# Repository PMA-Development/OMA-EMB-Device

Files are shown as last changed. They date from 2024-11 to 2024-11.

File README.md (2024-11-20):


<!-- PROJECT LOGO -->
<br />
<div align="center">
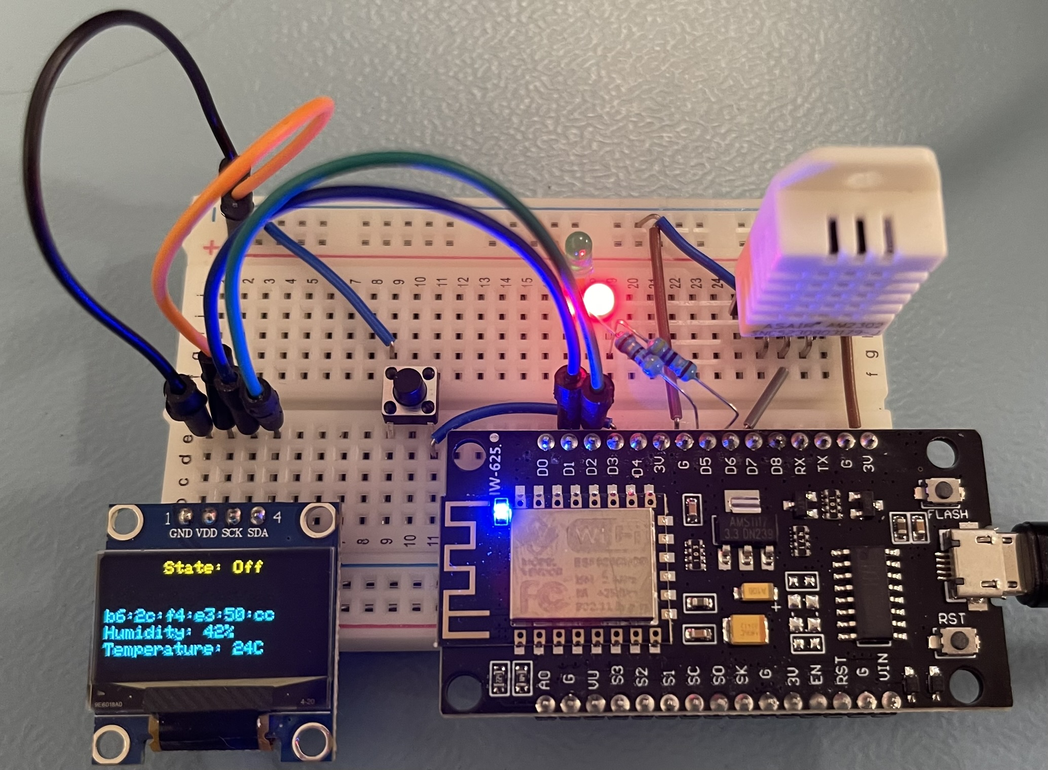
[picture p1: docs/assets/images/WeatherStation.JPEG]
Project image
    

  <h3 align="center">OMA - Embbedded Device sensors</h3>

  <p align="center">
    Weather Station, Generator and PowerDelivery sensor code for microcontroller.
    <br />
    <br />
  </p>
</div>

<!-- TABLE OF CONTENTS -->
<details>
  <summary>Table of Contents</summary>
  <ol>
    <li>
      <a href="#about-the-project">About The Project</a>
      <ul>
        <li><a href="#built-with">Built With</a></li>
      </ul>
    </li>
    <li><a href="#getting-started">Getting Started</a></li>
    <li><a href="#usage">Usage</a></li>
  </ol>
</details>

<!-- ABOUT THE PROJECT -->
## About The Project

### Libraries used

Here are the libaries used in this project, these libaries is a must have, to be able to run the program, please remember to install the dependencies!

* [ArduinoMqttClient 0.1.8](https://github.com/arduino-libraries/WiFiNINA) by [Arduino](https://www.arduinolibraries.info/authors/arduino-libraries)
* [Adafruit BusIO 1.16.2](https://github.com/adafruit/Adafruit_BusIO) by [Adafruit](https://www.arduinolibraries.info/authors/adafruit)
* [Adafruit GFX Library 1.11.11](https://github.com/adafruit/Adafruit-GFX-Library) by [Adafruit](https://www.arduinolibraries.info/authors/adafruit)
* [Adafruit SSD1306 2.5.13](https://github.com/adafruit/Adafruit_Sensor) by [Adafruit](https://www.arduinolibraries.info/authors/adafruit)
* [Adafruit Unified Sensor 1.1.4](https://github.com/adafruit/Adafruit_Sensor) by [Adafruit](https://www.arduinolibraries.info/authors/adafruit)
* [ArduinoJson 7.2.0](https://easybtn.earias.me/) by [Benoit Blanchon](https://github.com/bblanchon)
* [DHT sensor library 1.4.6](https://github.com/adafruit/DHT-sensor-library) by [Adafruit](https://www.arduinolibraries.info/authors/adafruit)
* [Effortless-SPIFFS 2.3.0](https://thebigpotatoe.github.io/Effortless-SPIFFS/) by [thebigpotatoe](https://github.com/thebigpotatoe)
* [WiFiManager 2.0.17](https://github.com/tzapu/WiFiManager) by [tzapu](https://www.arduino.cc/reference/en/libraries)

<p align="right">(<a href="#readme-top">back to top</a>)</p>

<!-- GETTING STARTED -->
## Getting Started
To get started, you will need [Arduino IDE 2.3.3](https://www.arduino.cc/en/software) and then follow the [Steps to Setup Arduino IDE for NODEMCU ESP8266](https://www.instructables.com/Steps-to-Setup-Arduino-IDE-for-NODEMCU-ESP8266-WiF/).

When you ahve the software installed, then you can move onto cloning the code down into your work folder, and open it with the Arduino IDE. After that, please continue reading the sections under.

## Connecting to WiFi and the MQTT broker.
After flashing the code to the ESP8266, a Wi-Fi AP will now be visible, connect to the Wi-Fi, and a config portel will apear shortly after. In the config portal, you most follow these steps:
1. Setup: Please fill in the DCP MQTT Broker credentials, and leave the ClientId blank, to use the MAC address of the WI-Fi module.
2. Save and go back to the main page.
3. Wi-Fi: Click into the wifi settings, and configure the Wi-Fi.
4. Click Save: Wait for the device to connect to the Wi-Fi and broker (May need to restart).

<p align="right">(<a href="#readme-top">back to top</a>)</p>

## Diagram / connection diagram
This diagram shows how to connect the different modules / components to the ESP8266.

All the sensor types has 2x LEDS, that is used for the sensor states, and is controlled with the ChangeState action.
Green LED for "On", rd LED for "Off" and the build in LED for "ServiceMode"

### Weather Station - ESP8266
This this is the weather station sensor, that deliveres weather data.

Code can be found in folder: WeatherStation

ESP8266 Weather Station

#### Data sample
```JSON
{
    "Id": "MyDevice",
    "Type": "WeatherTemperature",
    "Attributes": [
        {
            "Name": "Temperature",
            "Value": 24
        }
    ]
}
{
    "Id": "MyDevice",
    "Type": "WeatherHumidity",
    "Attributes": [
        {
            "Name": "Humidity",
            "Value": 60
        }
    ]
}
```

#### Pin connection

<ul>
  <li>
    <a href="https://ardustore.dk/produkt/display-oled-0-96-i2c-128x64-module-blaa-og-gul">Display OLED 0.96″ I2C 128×64 Module</a>
    <ul>
        I2C
        <li><strong>GND</strong> to <strong>GND</strong></li>
        <li><strong>VCC</strong> to <strong>3.3V</strong></li>
        <li><strong>SCK</strong> to pin <strong>D1</strong> on ESP8266</li>
        <li><strong>SDA</strong> to pin <strong>D2</strong> on ESP8266</li>
    </ul>
  </li>
  <li>
    <a href="https://ardustore.dk/produkt/led-diode-kit-3mm-and-5mm-375-dele">Green LED</a>
    <ul>
        <li><strong>+</strong> to <strong>47 Ω</strong></li>
        <li><strong>-</strong> to <strong>GND</strong></li>
        <li><strong>47 Ω</strong> to <strong>D5</strong></li>
    </ul>
  </li>
  <li>
    <a href="https://ardustore.dk/produkt/led-diode-kit-3mm-and-5mm-375-dele">Red LED</a>
    <ul>
        <li><strong>+</strong> to <strong>47 Ω</strong></li>
        <li><strong>-</strong> to <strong>GND</strong></li>
        <li><strong>47 Ω</strong> to <strong>D6</strong></li>
    </ul>
  </li>
  <li>
    <a href="https://ardustore.dk/produkt/tactile-push-button-switch-180-dele">Tactile Push Button Switch</a>
    <ul>
        <li><strong>Side 1</strong> to <strong>GND</strong></li>
        <li><strong>Side 2</strong> to <strong>D3</strong></li>
    </ul>
  </li>
  <li>
    <a href="https://ardustore.dk/produkt/dht-22-temperatur-fugtigheds-module">DHT-22</a>
    <ul>
    Communication Process: Serial Interface (Single-Wire Two-Way)
    <br/>
        <li><strong>SDA</strong> to <strong>SDA</strong> on ESP8266</li>
        <li><strong>GND</strong> to <strong>GND</strong></li>
        <li><strong>VCC</strong> to <strong>3.3V</strong></li>
        <li><strong>Signal</strong> to pin <strong>D7</strong> on ESP8266</li>
    </ul>
  </li>
</ul>

<p align="right">(<a href="#readme-top">back to top</a>)</p>

### Generator - ESP8266
This sensor meassueres the voltage of the generator of the turbine.

Code can be found in folder: Generator

ESP8266 Generator Voltage

#### Data sample
```JSON
{
    "Id": "MyDevice",
    "Type": "Generator",
    "Attributes": [
        {
            "Name": "Voltage",
            "Value": 1.36
        }
    ]
}
```

#### Pin connection
<ul>
  <li>
    <a href="https://ardustore.dk/produkt/led-diode-kit-3mm-and-5mm-375-dele">Green LED</a>
    <ul>
        <li><strong>+</strong> to <strong>47 Ω</strong></li>
        <li><strong>-</strong> to <strong>GND</strong></li>
        <li><strong>47 Ω</strong> to pin <strong>D5</strong> on ESP8266</li>
    </ul>
  </li>
  <li>
    <a href="https://ardustore.dk/produkt/led-diode-kit-3mm-and-5mm-375-dele">Red LED</a>
    <ul>
        <li><strong>+</strong> to <strong>47 Ω</strong></li>
        <li><strong>-</strong> to <strong>GND</strong></li>
        <li><strong>47 Ω</strong> to pin <strong>D6</strong> on ESP8266</li>
    </ul>
  </li>
  <li>
    <a href="https://ardustore.dk/produkt/tactile-push-button-switch-180-dele">Tactile Push Button Switch</a>
    <ul>
        <li><strong>Side 1</strong> to <strong>GND</strong></li>
        <li><strong>Side 2</strong> to pin <strong>D3</strong> on ESP8266</li>
    </ul>
  </li>
  <li>
    <a href="">Power Source</a>
    <ul>
        <li><strong>-</strong> to <strong>GND</strong></li>
        <li><strong>+</strong> to pin <strong>A0</strong> on ESP8266</li>
    </ul>
  </li>
</ul>

### PowerDelivery - ESP8266
This Sensor type meassueres the power deliveret from the turbine to the grid.

Code can be found in folder: PowerDelivery

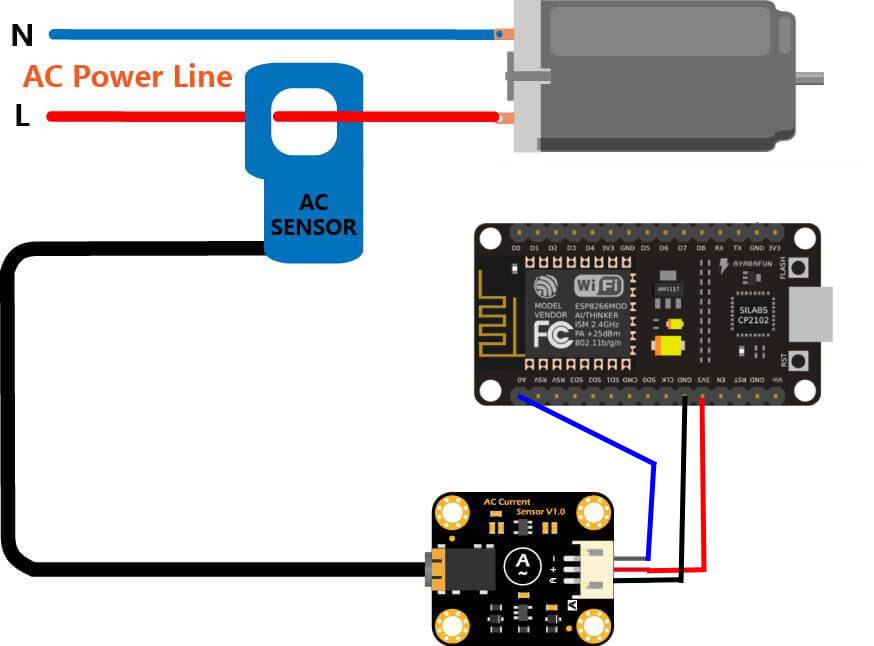
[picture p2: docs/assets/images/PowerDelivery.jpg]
DFROBOT Sketch


#### Data sample
```JSON
{
    "Id": "MyDevice",
    "Type": "PowerDelivery",
    "Attributes": [
        {
            "Name": "amp",
            "Value": 2.36
        }
    ]
}
```

#### Pin connection

<ul>
  <li>
    <a href="https://ardustore.dk/produkt/led-diode-kit-3mm-and-5mm-375-dele">Green LED</a>
    <ul>
        <li><strong>+</strong> to <strong>47 Ω</strong></li>
        <li><strong>-</strong> to <strong>GND</strong></li>
        <li><strong>47 Ω</strong> to pin <strong>D5</strong> on ESP8266</li>
    </ul>
  </li>
  <li>
    <a href="https://ardustore.dk/produkt/led-diode-kit-3mm-and-5mm-375-dele">Red LED</a>
    <ul>
        <li><strong>+</strong> to <strong>47 Ω</strong></li>
        <li><strong>-</strong> to <strong>GND</strong></li>
        <li><strong>47 Ω</strong> to pin <strong>D6</strong> on ESP8266</li>
    </ul>
  </li>
  <li>
    <a href="https://ardustore.dk/produkt/tactile-push-button-switch-180-dele">Tactile Push Button Switch</a>
    <ul>
        <li><strong>Side 1</strong> to <strong>GND</strong></li>
        <li><strong>Side 2</strong> to pin <strong>D3</strong> on ESP8266</li>
    </ul>
  </li>
  <li>
    <a href="https://www.dfrobot.com/product-1486.html">Gravity: Analog AC Current Sensor (20A)</a>
    <ul>
        <li><strong>-</strong> to <strong>GND</strong></li>
        <li><strong>+</strong> to pin <strong>A0</strong> on ESP8266</li>
    </ul>
  </li>
</ul>

## MQTT - Topics

### Subsciption

#### device/outbound/ping
Ping from Central server, where the device responds with a beacon on topic: device/inbound/beacon.
#### device/outbound/{clientId}/settings
```JSON
{ 
    "CollectionInterval": 5 // seconds.
}
```
#### device/outbound/{clientId}/changestate
to change the state of the sensor
```JSON
{ 
    "Value": "On" // options: ["On", "Off", "ServiceMode"]
}
```

### Publish
#### telemetry
Endpoint for telemetry data - QoS: 0.
```JSON
{
    "Id": "MyDevice",
    "Type": "MyType",
    "Attributes": [
        {
            "Name": "MyAttribyte",
            "Value": 1
        }
    ]
}
```

#### device/inbound/beacon
Device beacon - QoS: 0.
```JSON
{
    "Id": "MyDevice",
    "Type": "Weather",
    "State": "On",
    "CollectionInterval": 5,
}
```

#### device/inbound/beacon
Last will and testament - QoS: 1.
```JSON
{
    "Id": "MyDevice",
    "Type": "Weather",
    "State": "On",
    "CollectionInterval": 5,
}
```

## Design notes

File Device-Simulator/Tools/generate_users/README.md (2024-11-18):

# User generation for EMQX
This generation scripts creates userses to import into EMQX, and a json file to copy into appsettings.json, to use with the device simulator

## How to use
The script creates 10 users as default. To change the quantity of users, please open the script, and change the variable "users_to_create". Else just rung the script by: python3 ./generate_users.py

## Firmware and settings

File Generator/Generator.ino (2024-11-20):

#include <WiFiManager.h> // https://github.com/tzapu/WiFiManager
#include <ArduinoMqttClient.h>
#include <ArduinoJson.h>
#include <Effortless_SPIFFS.h>

// ######## WI-Fi Manager ########
#define TRIGGER_PIN 0 // Button to trigger ConfigPortal
#define SSID_NAME "SensorAP-2"
#define SSID_PWD "password"
#define CLOSE_PORTAL_AFTER 30 // How long the portal should stay open.

// ######## Configuration ########
#define JSON_CONFIG_FILE "/config.json"

// ######## MQTT ########
#define MQTT_TOPIC_PING "device/outbound/ping"
#define MQTT_TOPIC_BEACON "device/inbound/beacon"
#define MQTT_TOPIC_LAST_WILL "device/inbound/lastwill"
#define MQTT_TOPIC_DEVICE_ROOT "device/outbound/"

// ######## State LEDS ########
#define LED_OFF 12
#define LED_ON 14
#define LED_SERVICE_MODE BUILTIN_LED

// off = 0, on = 1, serviceMode = 2
int sensorState = 0;

int telemetryDelay = 2000; // milli Seconds
unsigned int lastTelemetryUpdate = 0;

// Config Related
eSPIFFS fileSystem;
bool shouldSaveConfig = false;

// wifimanager can run in a blocking mode or a non blocking mode
// Be sure to know how to process loops with no delay() if using non blocking
bool wm_nonblocking = false; // change to true to use non blocking

WiFiManager wm; // global wm instance
WiFiManagerParameter field_mqtt_host; // global param ( for non blocking w params )
WiFiManagerParameter field_mqtt_port; // global param ( for non blocking w params )
WiFiManagerParameter field_mqtt_client_id; // global param ( for non blocking w params )
WiFiManagerParameter field_mqtt_username; // global param ( for non blocking w params )
WiFiManagerParameter field_mqtt_pwd; // global param ( for non blocking w params )

// Network Related
byte mac[6];
String macAddressStr = "";

// MQTT related
WiFiClient wifiClient;
MqttClient mqttClient(wifiClient);
int publishTelemetryDelay = 5000; // milli Seconds
unsigned int lastTelemetryPublish = 0;
String mqttTopicDevice = "";

String mqttHost             = "";
int    mqttPort             = 1883;
String mqttTelemetryTopic   = "telemetry";
String mqttClientId         = "";
String mqttUsername         = "";
String mqttPassword         = "";

const int analogVoltagePin = A0;  // ESP8266 Analog Pin ADC0 = A0
int sensorValue = 0;  // value read from the pot
float outputValue = 0;  // value to output to a PWM pin


float readDCVoltage()
{
  float value = float(map(sensorValue, 0, 1024, 0, 3000))/ 1000.0;
  // Fix unstable reading, because resistor does not stabilize the reading.
  if (value < 0.1) {
    return 0.0;
  }
  return value;
}

void saveConfigFile() {
  Serial.println("Saving Config file...");

  StaticJsonDocument<512> jsonConfig;
  jsonConfig["mqttHost"] = mqttHost;
  jsonConfig["mqttPort"] = mqttPort;
  jsonConfig["mqttClientId"] = mqttClientId;
  jsonConfig["mqttUsername"] = mqttUsername;
  jsonConfig["mqttPassword"] = mqttPassword;
  jsonConfig["sensorState"] = sensorState;
  jsonConfig["telemetryDelay"] = telemetryDelay;

  String jsonData = "";
  serializeJson(jsonConfig, jsonData);
  serializeJson(jsonConfig, Serial);

  if (fileSystem.saveToFile(JSON_CONFIG_FILE, jsonData)) {
    Serial.println("Successfully wrote data to file");
    shouldSaveConfig = false;
  }
  else {
    Serial.println("Failed to write data to file");
  }
}

bool loadConfigFile()
// Load existing configuration file
{
  // Uncomment if we need to format filesystem
  // SPIFFS.format();
 
  // Read configuration from FS json
  Serial.println("Mounting File System...");

  String jsonData = "";
  if (fileSystem.openFromFile(JSON_CONFIG_FILE, jsonData)) {
    StaticJsonDocument<512> json;
    DeserializationError error = deserializeJson(json, jsonData);
    serializeJsonPretty(json, Serial);
    if (!error)
    {
      Serial.println("Parsing JSON");

      char host[20] = "";
      strcpy(host, json["mqttHost"]);
      mqttHost = String(host);
      mqttPort = json["mqttPort"].as<int>();
      char clientId[20] = "";
      strcpy(clientId, json["mqttClientId"]);
      mqttClientId = String(clientId);
      char username[20] = "";
      strcpy(username, json["mqttUsername"]);
      mqttUsername = String(username);
      char password[20] = "";
      strcpy(password, json["mqttPassword"]);
      mqttPassword = String(password);
      sensorState = json["sensorState"];
      telemetryDelay = json["telemetryDelay"];

      // avoid reading lower then 1 sec.
      if (telemetryDelay < 1000) {
        telemetryDelay = 1000;
      }

      return true;
    }
    else
    {
      // Error loading JSON data
      Serial.println("Failed to load json config");
    }
  }
 
  return false;
}

void saveConfigCallback()
// Callback notifying us of the need to save configuration
{
  Serial.println("Should save config");
  shouldSaveConfig = true;
}

void setupLEDs() {
  pinMode(LED_OFF, OUTPUT);
  pinMode(LED_ON, OUTPUT);
  pinMode(LED_SERVICE_MODE, OUTPUT);
}

void getMacAddress() {
  WiFi.macAddress(mac);
  macAddressStr += String(mac[5], HEX) + ":";
  macAddressStr += String(mac[4], HEX) + ":";
  macAddressStr += String(mac[3], HEX) + ":";
  macAddressStr += String(mac[2], HEX) + ":";
  macAddressStr += String(mac[1], HEX) + ":";
  macAddressStr += String(mac[0], HEX);
  Serial.println("MAC: " + macAddressStr);
}


void setup() {
  WiFi.mode(WIFI_STA); // explicitly set mode, esp defaults to STA+AP  
  Serial.begin(115200);
  Serial.setDebugOutput(true);  
  delay(3000);
  Serial.println("\n Starting");

  // displaySetup();
  setupLEDs();

  // Change to true when testing to force configuration every time we run
  bool forceConfig = false;

  bool spiffsSetup = loadConfigFile();
  if (!spiffsSetup)
  {
    Serial.println(F("Forcing config mode as there is no saved config"));
    forceConfig = true;
  }

  pinMode(TRIGGER_PIN, INPUT);
  
  // wm.resetSettings(); // wipe settings

  // Set config save notify callback
  wm.setSaveConfigCallback(saveConfigCallback);

  if(wm_nonblocking) wm.setConfigPortalBlocking(false);

  // add a custom input field
  int customFieldLength = 40;


  new (&field_mqtt_host) WiFiManagerParameter("field_mqtt_host", "MQTT Host", "", customFieldLength,"placeholder=\"\"");
  wm.addParameter(&field_mqtt_host);
  new (&field_mqtt_port) WiFiManagerParameter("field_mqtt_port", "MQTT Port", "1883", customFieldLength,"placeholder=\"\"");
  wm.addParameter(&field_mqtt_port);
  new (&field_mqtt_client_id) WiFiManagerParameter("field_mqtt_client_id", "MQTT Client ID", "", customFieldLength,"placeholder=\"\"");
  wm.addParameter(&field_mqtt_client_id);
  new (&field_mqtt_username) WiFiManagerParameter("field_mqtt_username", "MQTT Username", "", customFieldLength,"placeholder=\"\"");
  wm.addParameter(&field_mqtt_username);
  new (&field_mqtt_pwd) WiFiManagerParameter("field_mqtt_pwd", "MQTT Password", "", customFieldLength,"placeholder=\"\"");
  wm.addParameter(&field_mqtt_pwd);

  wm.setSaveParamsCallback(saveParamCallback);

  // custom menu via array or vector
  // 
  // menu tokens, "wifi","wifinoscan","info","param","close","sep","erase","restart","exit" (sep is seperator) (if param is in menu, params will not show up in wifi page!)
  // const char* menu[] = {"wifi","info","param","sep","restart","exit"}; 
  // wm.setMenu(menu,6);
  std::vector<const char *> menu = {"wifi","info","param","sep","restart","exit"};
  wm.setMenu(menu);

  // set dark theme
  wm.setClass("invert");

  wm.setConfigPortalTimeout(CLOSE_PORTAL_AFTER); // auto close configportal after n seconds
  wm.setAPClientCheck(true); // avoid timeout if client connected to softap

  bool res;
  // res = wm.autoConnect(); // auto generated AP name from chipid
  // res = wm.autoConnect("AutoConnectAP"); // anonymous ap
  res = wm.autoConnect(SSID_NAME,SSID_PWD); // password protected ap

  if(!res) {
    Serial.println("Failed to connect or hit timeout");
    ESP.restart();
  } 
  else {
    //if you get here you have connected to the WiFi    
    Serial.println("connected to Wi-Fi... :)");
  }

  Serial.println("WiFi connected");
  Serial.print("IP Address: ");
  Serial.println(WiFi.localIP());

  Serial.print("Custom Field MQTT Host: ");
  Serial.println(mqttHost);

  Serial.print("Custom Field MQTT Port: ");
  Serial.println(mqttPort);

  Serial.print("Custom Field MQTT Client ID: ");
  Serial.println(mqttClientId);

  Serial.print("Custom Field MQTT Username: ");
  Serial.println(mqttUsername);

  Serial.print("Custom Field MQTT Password: ");
  Serial.println(mqttPassword);

  // Save the custom parameters to FS
  if (shouldSaveConfig)
  {
    saveConfigFile();
  }

  updateLEDs();

  getMacAddress();
  if (mqttClientId.length() == 0) {
    mqttClientId = macAddressStr;
  }
}

void updateLEDs() {
  if (sensorState == 0) {
    digitalWrite(LED_OFF, HIGH);
    digitalWrite(LED_ON, LOW);
    digitalWrite(LED_SERVICE_MODE, LOW);
  }
  else if (sensorState == 1) {
    digitalWrite(LED_ON, HIGH);
    digitalWrite(LED_OFF, LOW);
    digitalWrite(LED_SERVICE_MODE, LOW);
  }
  else if (sensorState == 2) {
    digitalWrite(LED_SERVICE_MODE, HIGH);
    digitalWrite(LED_OFF, LOW);
    digitalWrite(LED_ON, LOW);
  }
}

void readTelemetry() {
  if ((millis() - lastTelemetryUpdate) > telemetryDelay) {
    lastTelemetryUpdate = millis();
    sensorValue = analogRead(analogVoltagePin);
    // map it to the range of the PWM out
    outputValue = readDCVoltage();
    
    // print the readings in the Serial Monitor
    Serial.print("sensor = ");
    Serial.print(sensorValue);
    Serial.print("\t output = ");
    Serial.println(outputValue);

    if (!mqttClient.connected()) {
        connectToBroker();
        return;
      }
      else {
      }
      // Publish Telemetry data
      publishMqttTelemetry();
  }
}

void checkButton(){
  // check for button press
  if ( digitalRead(TRIGGER_PIN) == LOW ) {
    // poor mans debounce/press-hold, code not ideal for production
    delay(50);
    if( digitalRead(TRIGGER_PIN) == LOW ){
      Serial.println("Button Pressed");
      // still holding button for 3000 ms, reset settings, code not ideaa for production
      delay(3000); // reset delay hold
      if( digitalRead(TRIGGER_PIN) == LOW ){
        Serial.println("Button Held");
        Serial.println("Erasing Config, restarting");
        wm.resetSettings();
        ESP.restart();
      }
      
      // displaySetup();
      // start portal w delay
      Serial.println("Starting config portal");
      wm.setConfigPortalTimeout(120);
      
      if (!wm.startConfigPortal(SSID_NAME,SSID_PWD)) {
        Serial.println("failed to connect or hit timeout");
        delay(3000);
        // ESP.restart();
      } else {
        //if you get here you have connected to the WiFi
        Serial.println("connected...yeey :)");
      }
    }
  }
}


String getParam(String name){
  //read parameter from server, for customhmtl input
  String value;
  if(wm.server->hasArg(name)) {
    value = wm.server->arg(name);
  }
  return value;
}


bool connectToBroker() {
  if (mqttClientId.length() == 0) {
    Serial.println("ClientId missing, cannot connect to broker...");
    return false;
  }
  mqttClient.setId(mqttClientId);
  mqttClient.setUsernamePassword(mqttUsername, mqttPassword);

  if (!mqttClient.connect(mqttHost.c_str(), mqttPort)) {
    Serial.print("MQTT connection failed! Error code = ");
    Serial.println(mqttClient.connectError());
    return false;
  }
  // set the message receive callback
  mqttClient.onMessage(onMqttMessage);

  Serial.print("Subscribing to topic: ");
  Serial.println(MQTT_TOPIC_PING);
  mqttClient.subscribe(MQTT_TOPIC_PING);

  mqttTopicDevice = String(MQTT_TOPIC_DEVICE_ROOT) + mqttClientId + "/";
  Serial.print("Subscribing to topic: ");
  Serial.println(mqttTopicDevice + "#");
  mqttClient.subscribe(mqttTopicDevice + "#");

  mqttPublishBeacon();

  mqttLastWill();

  return true;
}

void saveParamCallback(){
  mqttHost = field_mqtt_host.getValue();
  String _portStr = field_mqtt_port.getValue();
  mqttPort = _portStr.toInt();
  mqttClientId = field_mqtt_client_id.getValue();
  mqttUsername = field_mqtt_username.getValue();
  mqttPassword = field_mqtt_pwd.getValue();
  if (mqttClientId.length() == 0) {
    mqttClientId = macAddressStr;
  }
  connectToBroker();
  // updateDisplay();
}

void publishMqttTelemetry(){
  if (!mqttClient.connected()) {
    if (!connectToBroker()) {
      return;
    }
  }
  StaticJsonDocument<200> doc;

  doc["Id"] = macAddressStr;
  doc["Type"] = "Generator";

  JsonArray jsonAttributeArr = doc.createNestedArray("Attributes");
  JsonObject jsonAttribute_0 = jsonAttributeArr.createNestedObject();
  jsonAttribute_0["Name"] = "Voltage";
  jsonAttribute_0["Value"] = outputValue;

  mqttClient.beginMessage(mqttTelemetryTopic);
  serializeJson(doc, mqttClient);
  serializeJson(doc, Serial);
  mqttClient.endMessage();
  Serial.println();
}

void mqttLastWill() {
  mqttClient.beginWill(MQTT_TOPIC_LAST_WILL, mqttClientId.length(), false, 1);
  mqttClient.print(mqttClientId);
  mqttClient.endWill();
}

void mqttPublishBeacon() {
  StaticJsonDocument<300> doc;
  doc["Id"] = mqttClientId;
  doc["Type"] = "Sensor";
  doc["CollectionInterval"] = telemetryDelay;
  if (sensorState == 0) {
    doc["State"] = "Off";
  }
  else if (sensorState == 1) {
    doc["State"] = "On";
  }
  else if (sensorState == 2) {
    doc["State"] = "ServiceMode";
  }

  mqttClient.beginMessage(MQTT_TOPIC_BEACON);
  serializeJson(doc, mqttClient);
  serializeJson(doc, Serial);
  mqttClient.endMessage();
  Serial.println();
}

void onMqttMessage(int messageSize) {
  // we received a message, print out the topic and contents
  String topic = mqttClient.messageTopic();
  Serial.println("Received a message with topic '");
  Serial.println(topic);

  String msg_message = mqttClient.readString();
  Serial.println(msg_message);

  StaticJsonDocument<512> doc;
  DeserializationError error = deserializeJson(doc, msg_message);
  if (!error){
    if (topic == MQTT_TOPIC_PING) {
      mqttPublishBeacon();
    }
    else if (topic == mqttTopicDevice + "settings") {
      if (doc.containsKey("CollectionInterval")) {
        telemetryDelay = doc["CollectionInterval"].as<int>() * 1000; // Convert sec to millies.
        shouldSaveConfig = true; // Save to config file;
      }
      else {
        Serial.println("Json does not contain key: CollectionInterval");
      }
    }
    else if (topic == mqttTopicDevice + "changestate") {
      if (doc.containsKey("Value")) {
        String state = doc["Value"];
        if (state == "Off") {
          sensorState = 0;
        }
        else if (state == "On") {
          sensorState = 1;
        }
        if (state == "ServiceMode") {
          sensorState = 2;
        }
        updateLEDs();
        shouldSaveConfig = true; // Save to config file;
      }
      else {
        Serial.println("Json does not contain key: Value");
      }
    }
    else {
      Serial.println("No topics matched!");
    }
  }
  else {
    // Error loading JSON data
    Serial.print("deserializeJson() failed with code ");
    Serial.println(error.c_str());
  }
  Serial.println();
  Serial.println();
}

void mqttHandler() {
  // call poll() regularly to allow the library to send MQTT keep alive which
  // avoids being disconnected by the broker
  mqttClient.poll();
}

void loop() {
  mqttHandler();
  if(wm_nonblocking) wm.process(); // avoid delays() in loop when non-blocking and other long running code  
  checkButton();
  // put your main code here, to run repeatedly:

  readTelemetry();
  if (shouldSaveConfig)
  {
    saveConfigFile();
  }
}

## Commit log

2024-11-12 [IMP] Weather station sensor
2024-11-14 [FIX] Save config file flag not reseting
    [WeatherStation.ino]
2024-11-14 [ADD] PowerDelivery code added
2024-11-18 [WIP] Implement genrator and powerdelivery
    [emqx_users_import.csv]
2024-11-18 [IMP] Updated README
    [Generator_Voltage_ESP8266.fzz, WeatherStation.fzz]
2024-11-19 [FIX] Writng to wrong doc
    [WeatherStation.ino]
